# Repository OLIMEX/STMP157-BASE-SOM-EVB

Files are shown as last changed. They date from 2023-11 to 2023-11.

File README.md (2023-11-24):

# STMP157-BASE-SOM-EVB
Evaluation board for STMP157-BASE-SOM

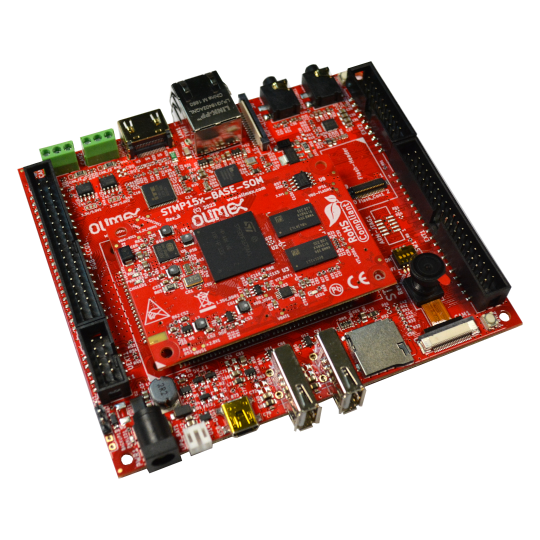
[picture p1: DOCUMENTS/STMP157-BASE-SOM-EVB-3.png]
STMP157-BASE-SOM-EVB-3


https://www.olimex.com/Products/SOM/STMP1/STMP157-BASE-SOM-EVB/open-source-hardware

## Features:

* 6 connectors for STMP157-BASE-SOM
* Two USB host 2.0
* USB-OTG
* Two CAN drivers
* HDMI output
* CSI OV2640-120 2Mpixel Camera
* Gigabit Ethernet
* MIPI LCD connector
* Microphone 3.5mm connector
* Headphones 3.5mm connector
* RESET button
* RGB LCD connector compatible with LCD-OLinuXino-5CTS, LCD-OLinuXino-7.0CTS, LCD-OLinuXino-10CTS
* UEXT connector
* EXT1, EXT2 connectors
* PWR connector
* LiPo charger and battery connector
* PWR LED
* DBG connector
* Flash module connector
* Boot configuration slide switch
* SD-card
* optional JTAG connector (not populated)
* Dimensions: 122 x 106 mm

## Licenses

* Hardware is released under CERN Open Hardware Licence Version 2 - Strongly Reciprocal, all silkscreen credits to Olimex should remain;
* Software is released under GPL3 Licensee
* Documentation is released under CC BY-SA 3.0

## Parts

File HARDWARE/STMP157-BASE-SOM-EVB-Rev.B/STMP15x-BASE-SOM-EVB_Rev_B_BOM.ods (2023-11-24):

Qty | Designation | Package | Designator
3 | 0R/R0402 | R_0402_5MIL_DWS | R86,R89,R90
1 | 10R/R0402 | R_0402_5MIL_DWS | R30
14 | 22R/R0402 | R_0402_5MIL_DWS | R12,R17,R18,R19,R22,R24,R41, R42,R67,R75,R76,R78,R81,R79
3 | 120R/R1206 | R_1206_5MIL_DWS | R37,R40,R50
3 | 330R/R0402 | R_0402_5MIL_DWS | R8,R46,R47
2 | 680R/R0402 | R_0402_5MIL_DWS | R48,R49
8 | 1k/R0402 | R_0402_5MIL_DWS | R55,R68,R69,R70,R71,R72, R74,R80
1 | 1.1k/1%/R0402 | R_0402_5MIL_DWS | R5
11 | 2.2k/R0402 | R_0402_5MIL_DWS | R3,R7,R9,R10,R11,R26,R27, R31,R34,R45,R51
1 | 5.6k/R0402 | R_0402_5MIL_DWS | R20
2 | 6.81k/1%/R0402 | R_0402_5MIL_DWS | R64,R65
1 | 8.25k/1%/R0402 | R_0402_5MIL_DWS | R4
22 | 10k/R0402 | R_0402_5MIL_DWS | R1,R6,R14,R16,R21,R25,R28, R29,R32,R33,R36,R39,R52,R57, R58,R59,R60,R62,R73,R77, R82,R85
1 | 12.1k/1%/R0603 | R_0603_5MIL_DWS | R53
1 | 13k/1%/R0402 | R_0402_5MIL_DWS | R63
2 | 100k/R0402 | R_0402_5MIL_DWS | R54,R83
1 | 1M/R0402 | R_0402_5MIL_DWS | R2
3 | RA0805_(4X0402)_22R | RA0805_(4X0402)_xx_BIGGEROUTPADS | RM1,RM3,RM4
1 | RA0805_(4X0402)_4.7k | RA0805_(4X0402)_xx_BIGGEROUTPADS | RM2
1 | RA1206_(4x0603)_4B8_100k | RA1206_(4X0603)_4B8_xx | RM5
2 | 33pF/50V/5%/COG/C0402 | C_0402_5MIL_DWS | C47,C48
1 | 1nF/2kV/10%/X7R/C1206 | C_1206_5MIL_DWS_ISO | C85
1 | 3.3nF/50V/10%/X5R/C0402 | C_0402_5MIL_DWS | C43
36 | 100nF/10V/10%/X5R/C0402 | C_0402_5MIL_DWS | C10,C11,C12,C14,C15,C17,C18, C19,C20,C21,C22,C23,C25,C28, C29,C33,C38,C39,C40,C41,C44, C45,C51,C53,C54,C56,C57,C59, C61,C62,C63,C77,C78,C79, C83,C84
1 | 1uF/10V/10%/X5R/C0603 | C_0603_5MIL_DWS | C64
7 | 10uF/6.3V/20%/X5R/C0603 | C_0603_5MIL_DWS | C7,C8,C26,C27,C34,C36,C37
10 | 22uF/6.3V/20%/X5R/C0603 | C_0603_5MIL_DWS | C1,C5,C9,C13,C16,C46,C49, C52,C58,C60
15 | 47uF/6.3V/20%/X5R/C0805 | C_0805_5MIL_DWS | C2,C3,C4,C30,C31,C35,C50, C55,C65,C66,C67,C68,C69, C70,C86
1 | 1N5822/SS34/SMA | SMA-KA | D1
1 | 1N4007/SMA | SMA-KA | D3
1 | 1N5819S4(SOD123) | SOD-123_1C-2A_KA | D4
1 | SMBJ6.0A | DO214AA_1(K)-2(A) | D2
1 | LED/Red/0603 | LED_0603_KA | PWRLED1
1 | 2.2uH/3A/YS75/7x8 | YS75_7X8MM | L1
9 | FB0805/600R/2A | L_0805_5MIL_DWS | L2,L3,L4,L5,L6,L7,L8,L9,L12
1 | BSS138(SOT-23) | SOT23 | FET2
2 | IRLML6402(SOT-23) | SOT23 | FET3,FET1
1 | Q25MHz/20pF/20ppm/ 4P/3.2x2.5mm | TSX-3.2x2.5mm_GND(3) | Q1
1 | FSMD035 | FUSE-1206 | FUSE2
2 | ESDS314DBVR(SOT-23-5) | SOT-23-5 | TVS1,TVS2
1 | IT66121FN(QFN-64) | QFN64_9x9mm_Pitch_0.5mm | U6
1 | KSZ9031RNXCC-TR/QFN48 | QFN48_1DRILL(PADPITCH-0.5MM) | U13
3 | SY6280AAC(SOT23-5) | SOT-23-5 | U10,U11,U12
2 | SIT1050T(SOIC-8_150mil) | SOIC-8_150mil | U8,U9
1 | MT3608(SOT23-6) | SOT23-6 | U2
1 | ES8388(QFN28) | QFN28_EP(29)_4.076x4.076x0.9m | U7
1 | VDA4510CTA(SOT23-3) | SOT-23 | U14
1 | LD1117AG-AD-AA3-A-R | SOT223 | VR1
1 | TFC-WPAPR-08-LF | TFC-WPAPR-08 | MICRO_SD1
1 | CAMERA-OV2640-120 (FPV-WZB21-24-LF) | OV2640(FPV-WZB21-24-LF) | CAM1
2 | USB_A_VERTICAL | USB_A_VERTICAL_PTH | USB1,USB2
1 | USB-OTG(MSB-SW-5AB-LF) | USB_MINI_9PIN | USB-OTG1
1 | DW02R | LIPO_BAT-CON2DW02R | LiPo_BAT1
1 | PWRJ-2mm(YDJ-1134) | PWRJ-2mm(YDJ-1134) | PWR1
1 | HN1x3 | HN1x3 | DBG1
2 | TB3-3.5mm(HD-351_3P) | TB3-3.5mm | CAN1,CAN2
1 | TM211Q01FM22 | TM211Q01FM22 | LAN1
1 | P-B-V-10-LF | GBH-254-SMT-10 | UEXT1
2 | P-B-V-40-LF | GBH-254-SMT-40 | EXT1,RGB-LCD1
1 | B-V-20-LF(GBH254SMT-20) | GBH-254-SMT-20 | EXT2
1 | FPA-VZA2-15-LF | TE_1-1734248-5 | MiPi-LCD1
2 | PJ-3.5-365-3P (SCJ325P00XG0B02G) | SCJ325P00XG0B02G | MICROPHONE1, HEADPHONES1
1 | DF12(3.0)-40DS-0.5V(51) | Flash_Con[DF12(3.0)-40DS-0.5V(86)] | Flash_Con1
6 | MALE-PAV16X-2x20-HIGH | GPH127SMT-02X20(PA-V16X-2X20-LF) | GPIO1,GPIO2,GPIO3,GPIO4, GPIO5,GPIO6
1 | HDMI-SWM-19 | HDMI-SWM-19 | HDMI1
1 | DSHP04TS-S | DSHP04TS-S-1.27mm_Half_4_Slide | BOOT_SW1
2 | YTS-A016-X | YTS-A016-X | RST1,PWR2
2 | Opened(2-3)/Closed(1-2) | SJ_2_SMALL_12_TIED | 3.3V/5.0V1,3.3V/5.0V2
3 | Opened | SJ_1_SMALLER | 5V_E1,CAN_T1,CAN_T2
1 | NA(10uF/6.3V/20%/X5R/C0603) | C_0603_5MIL_DWS | C6
2 | NA(100nF/10V/10%/X5R/C0402) | C_0402_5MIL_DWS | C32,C24
1 | NA(HN1X2) | HN1x2 | BACKUP1
1 | NA(15pF/C0402) | C_0402_5MIL_DWS | C42
2 | NA(2.2k/R0402) | R_0402_5MIL_DWS | R92,R91
10 | NA/R0402 | R_0402_5MIL_DWS | R61,R13,R15,R35,R38,R43,R44, R66,R56,R84
1 | NA(HAB-VCR-010-LF) | HAB-VCR-010-LF | ARM-JTAG1
3 | NA(24pF/50V/5%/COG/C0402) | C_0402_5MIL_DWS | C80,C82,C81
3 | NA(RCLAMP0524P(SLP2510P8)) | SLP2510P8_TEST | U5,U3,U4
1 | NA(22R/R0402) | R_0402_5MIL_DWS | R23
6 | NA(47uF/6.3V/20%/X5R/C0805) | C_0805_5MIL_DWS | C71,C72,C73,C74,C75,C76
1 | NA(5025) | FUSE-5025 | FUSE1
2 | NA(2.7nH/L0402) | L_0402_5MIL_DWS | L10,L11
1 | NA(MCP121T475I-TT(SOT23-3)) | SOT-23 | U1
4 | NA(560pF/50V/5%/NP0/C0603) | C_0603_5MIL_DWS | C87,C88,C89,C90
2 | NA(0R/R0402) | R_0402_5MIL_DWS | R87,R88

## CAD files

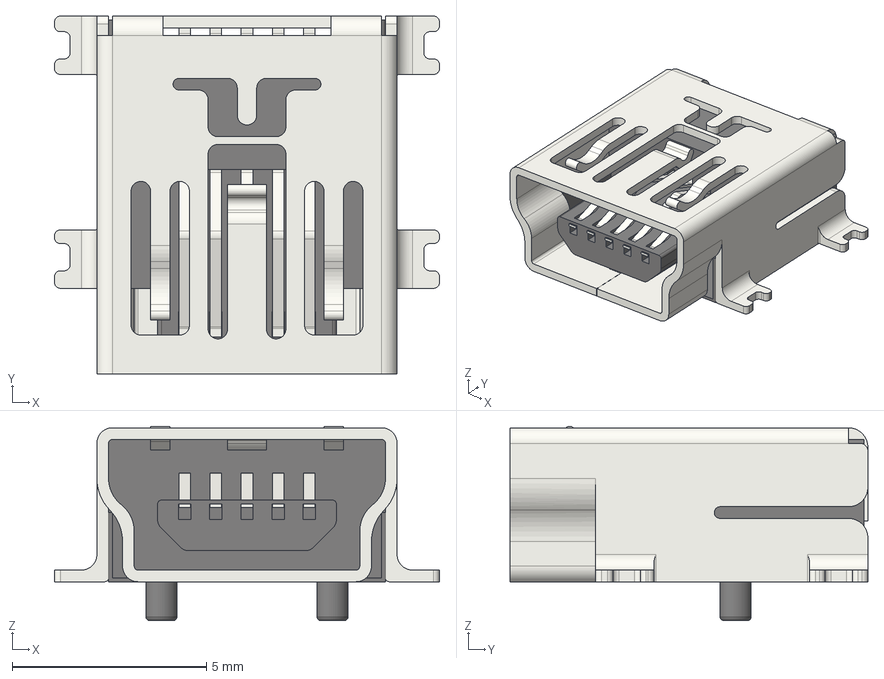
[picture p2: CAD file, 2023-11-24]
HARDWARE/STMP157-BASE-SOM-EVB-Rev.B/3d/USB_Mini-B_Lumberg_2486_01_Horizontal.step
9.90 x 9.20 x 5.00 mm

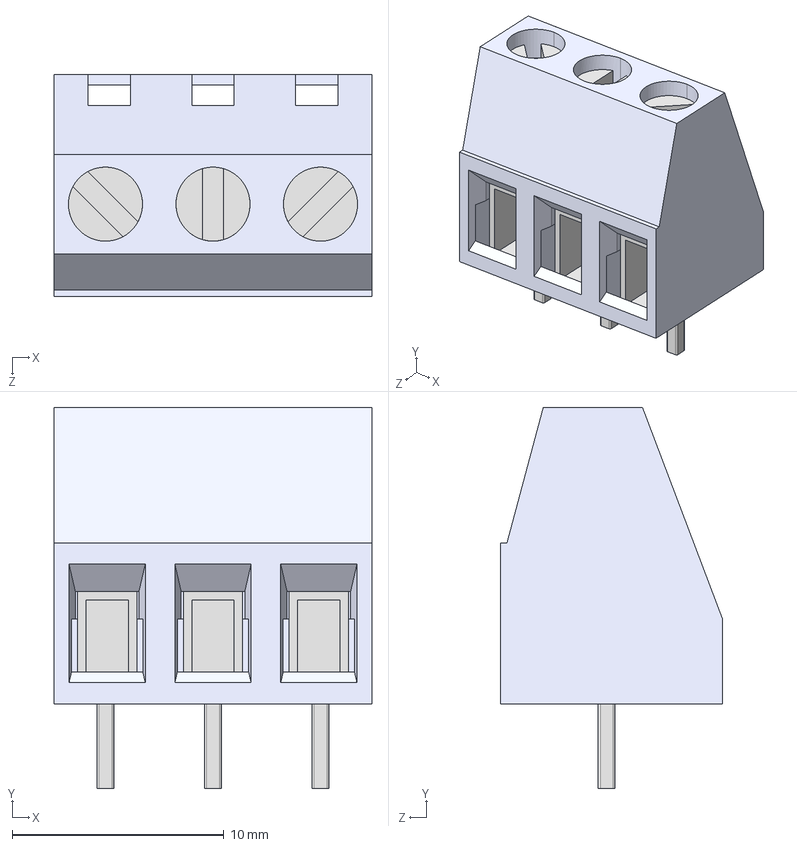
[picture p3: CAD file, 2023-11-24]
HARDWARE/STMP157-BASE-SOM-EVB-Rev.B/3d/klema-5mm-3pin.step
15.0 x 18.0 x 10.5 mm

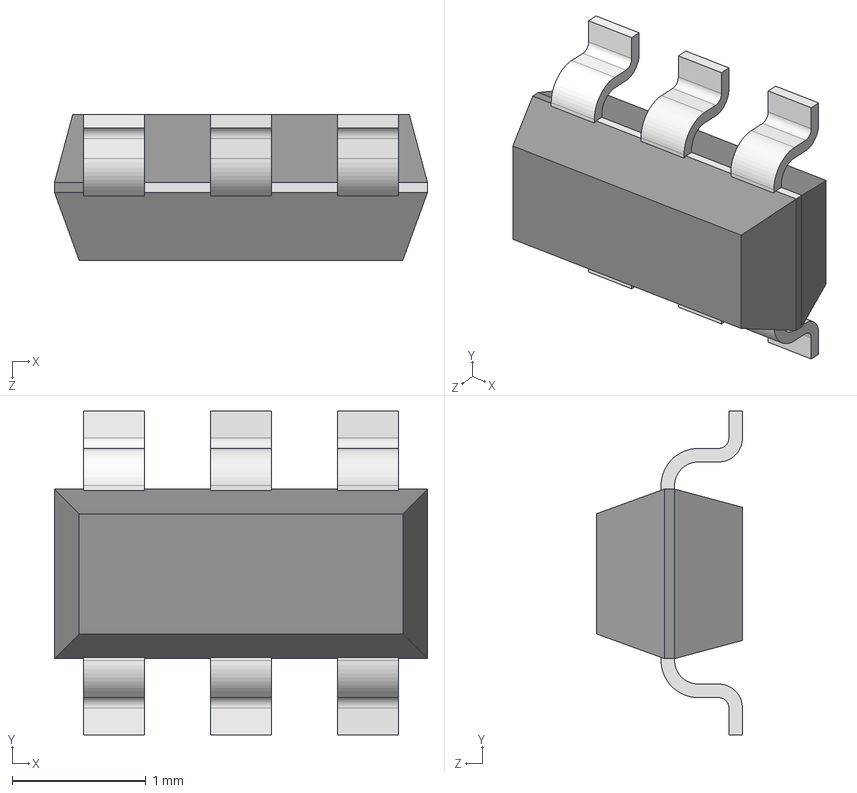
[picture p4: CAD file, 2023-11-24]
HARDWARE/STMP157-BASE-SOM-EVB-Rev.B/3d/SOT-23-6.step
2.79 x 2.43 x 1.09 mm

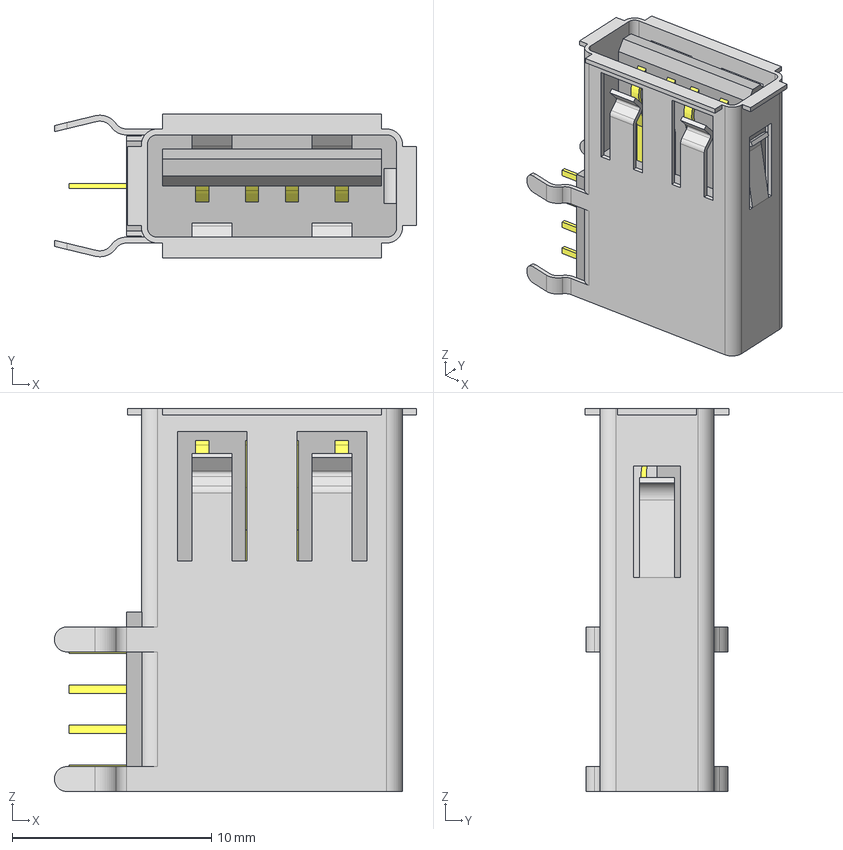
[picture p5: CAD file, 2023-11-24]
HARDWARE/STMP157-BASE-SOM-EVB-Rev.B/3d/USB-A-S-F-B-VU.stp
18.2 x 7.20 x 19.2 mm
_USB-A-S-VU_S
_USB-A-S-B-VU_B
_USB-A-S-VU_P

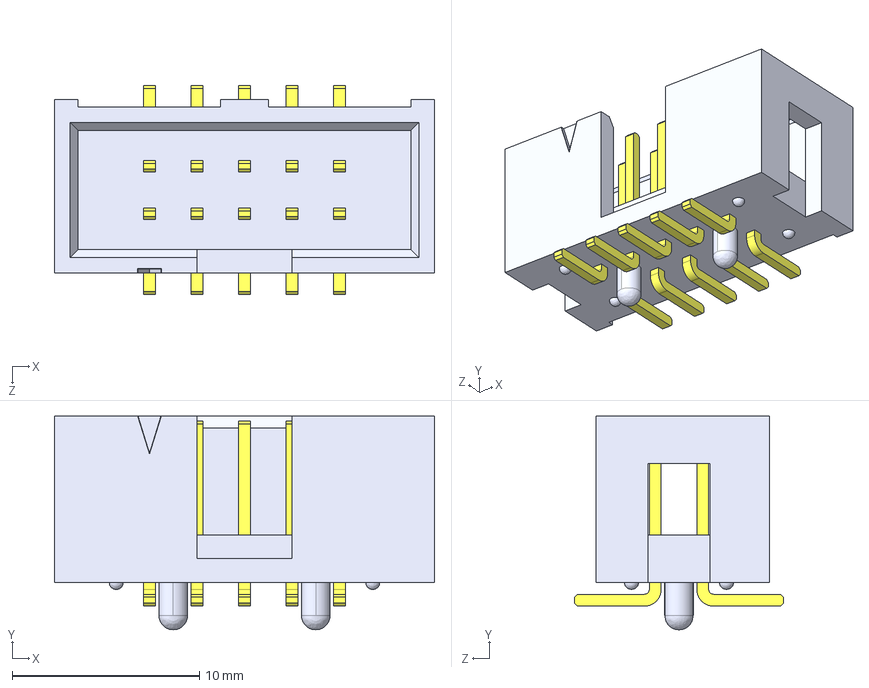
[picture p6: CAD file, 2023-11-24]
HARDWARE/STMP157-BASE-SOM-EVB-Rev.B/3d/UEXT-SMD.STEP
20.3 x 11.4 x 11.2 mm
User Library-HTST-105-01-F-DV-A__HTST-105-01-DV-A_header
User Library-HTST-105-01-F-DV-A__HTST-First_Position_Indicator
User Library-HTST-105-01-F-DV-A__T-1S6-05-01-DV_

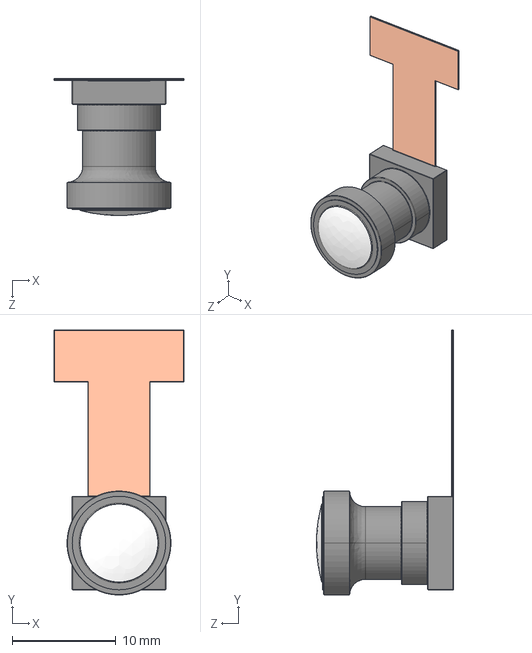
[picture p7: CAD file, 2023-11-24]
HARDWARE/STMP157-BASE-SOM-EVB-Rev.B/3d/OV2640.STEP
12.5 x 25.5 x 13.2 mm

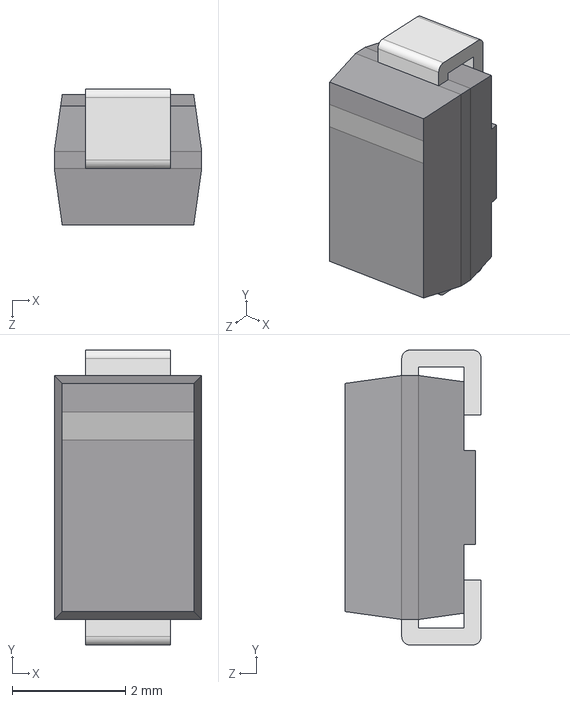
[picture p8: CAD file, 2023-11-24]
HARDWARE/STMP157-BASE-SOM-EVB-Rev.B/3d/DO-214AC_SMA.step
2.60 x 5.20 x 2.40 mm

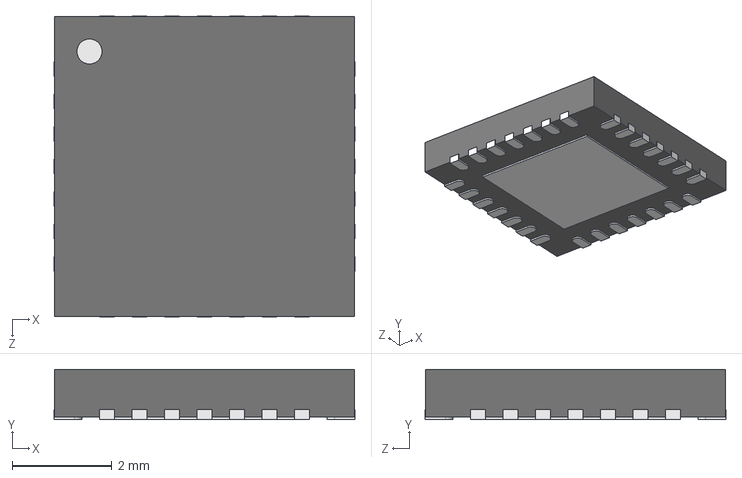
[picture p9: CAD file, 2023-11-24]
HARDWARE/STMP157-BASE-SOM-EVB-Rev.B/3d/QFN-28(6.0x6.0x1.0mm_P0.65mm).STEP
6.02 x 1.00 x 6.02 mm

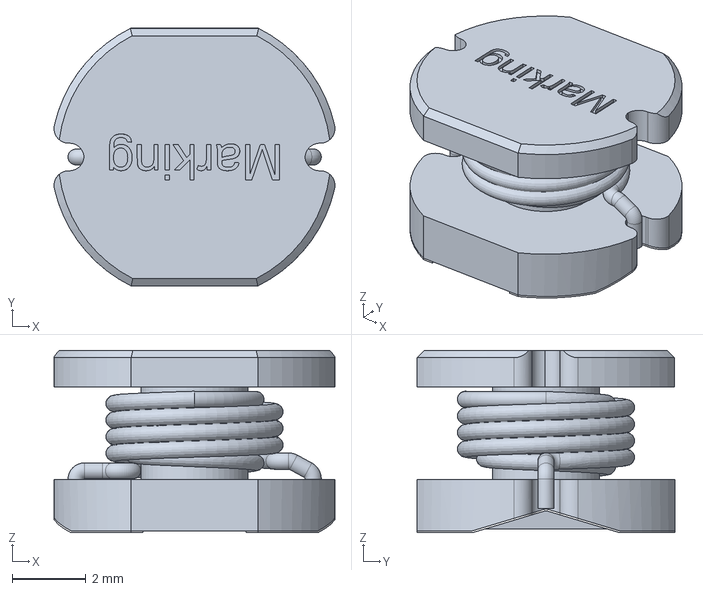
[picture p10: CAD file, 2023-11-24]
HARDWARE/STMP157-BASE-SOM-EVB-Rev.B/3d/L-CD75(YS75)_7.80x7.00x5.50mm.step
7.63 x 7.00 x 4.95 mm

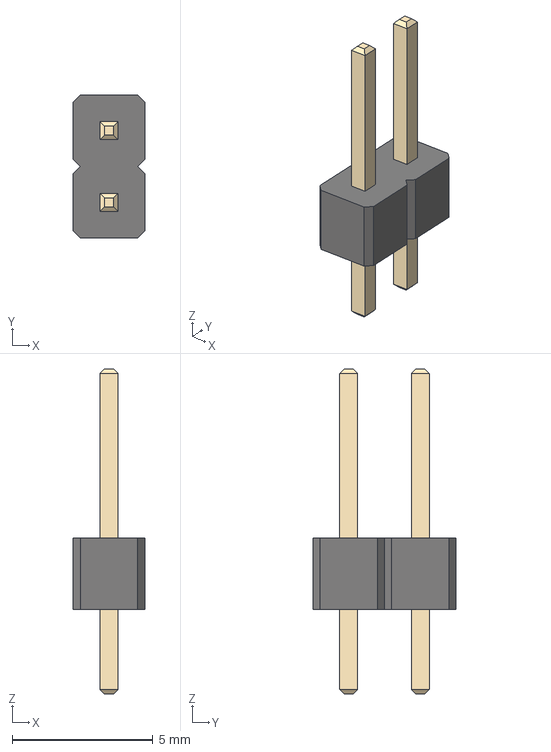
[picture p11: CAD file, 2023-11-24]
HARDWARE/STMP157-BASE-SOM-EVB-Rev.B/3d/HN1x2-PinHeader_1x02_P2.54mm_Vertical.step
2.54 x 5.08 x 11.5 mm

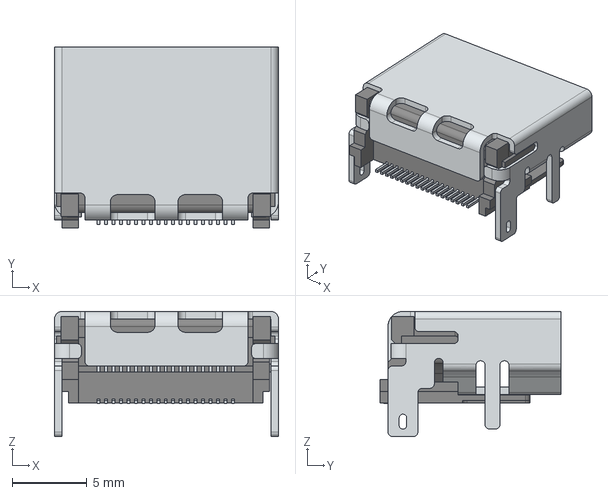
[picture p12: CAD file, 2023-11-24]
HARDWARE/STMP157-BASE-SOM-EVB-Rev.B/3d/HDMI_19POS_SMD_Wurth_Electronic-685119134923.stp
15.0 x 12.2 x 8.38 mm

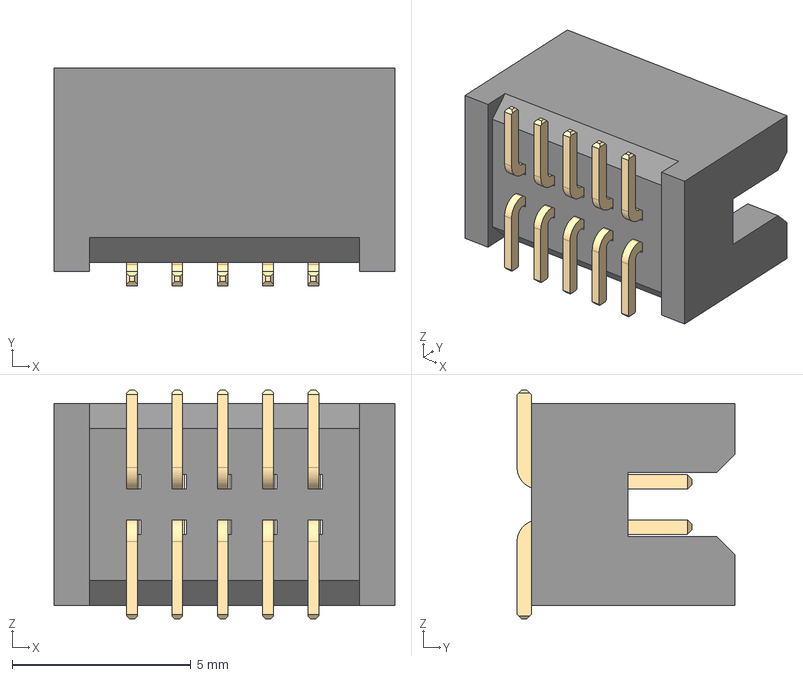
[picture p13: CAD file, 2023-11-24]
HARDWARE/STMP157-BASE-SOM-EVB-Rev.B/3d/GBH2x5.stp
9.55 x 6.10 x 6.40 mm

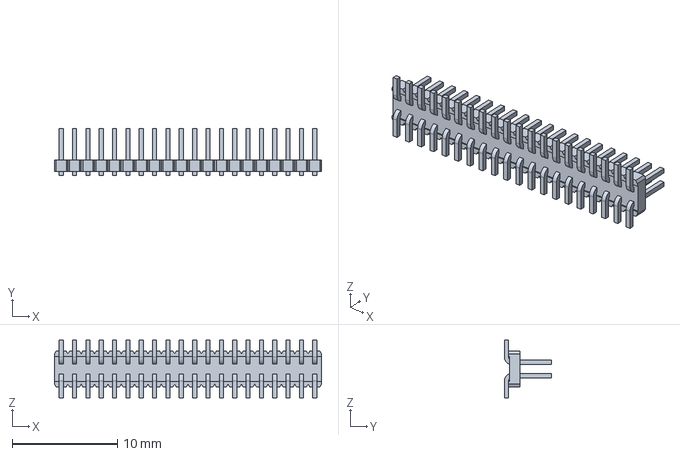
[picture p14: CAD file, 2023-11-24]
HARDWARE/STMP157-BASE-SOM-EVB-Rev.B/3d/40PinMaleSMD.stp
25.4 x 4.50 x 5.50 mm

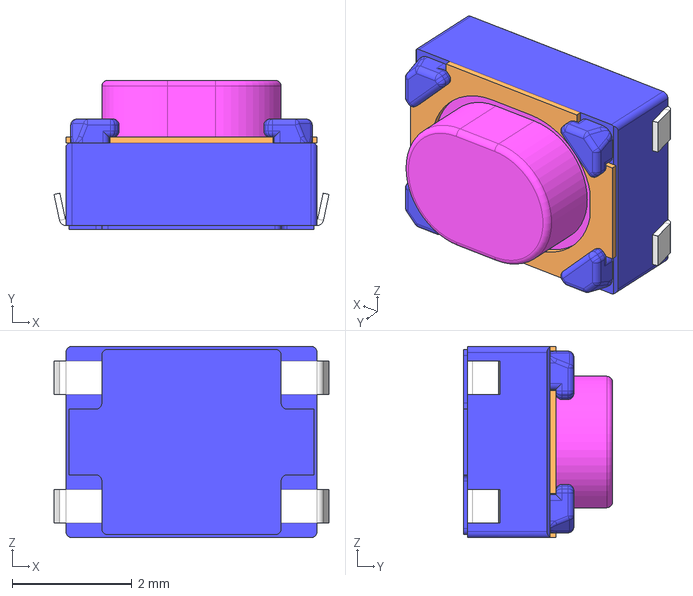
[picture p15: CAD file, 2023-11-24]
HARDWARE/STMP157-BASE-SOM-EVB-Rev.B/3d/YTS-A016-X(SKRPABE010).stp
4.60 x 2.50 x 3.20 mm

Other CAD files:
HARDWARE/STMP157-BASE-SOM-EVB-Rev.B/3d/SOT-23.step
HARDWARE/STMP157-BASE-SOM-EVB-Rev.B/3d/HN1x3-PinHeader_1x03_P2.54mm_Vertical.step
HARDWARE/STMP157-BASE-SOM-EVB-Rev.B/3d/dshp04ts-s.stp
HARDWARE/STMP157-BASE-SOM-EVB-Rev.B/3d/QFN48-0.5.STEP
HARDWARE/STMP157-BASE-SOM-EVB-Rev.B/3d/Audio_Jack-3.5mm---CUI_SJ1-3515-SMT-TR.step
HARDWARE/STMP157-BASE-SOM-EVB-Rev.B/3d/Connector_1Port_RJ45_Magjack_10-100Base-T_AutoMDIX_Molex-0934635206_DigiKey-WM17614-ND.stp
HARDWARE/STMP157-BASE-SOM-EVB-Rev.B/3d/DF12(3.0)-40DS-0.5V.stp
HARDWARE/STMP157-BASE-SOM-EVB-Rev.B/3d/DO-214AA_SMB.step
HARDWARE/STMP157-BASE-SOM-EVB-Rev.B/3d/FPV-WZB21-24-LF_Molex-524372433.stp
HARDWARE/STMP157-BASE-SOM-EVB-Rev.B/3d/GBH254SMT-20(B-V-20-LF)---CH8720xM100.STEP
HARDWARE/STMP157-BASE-SOM-EVB-Rev.B/3d/GBH254SMT-40(B-V-40-LF).stp
HARDWARE/STMP157-BASE-SOM-EVB-Rev.B/3d/JST_B2B-PH-SM4-TB(DW02R).step
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

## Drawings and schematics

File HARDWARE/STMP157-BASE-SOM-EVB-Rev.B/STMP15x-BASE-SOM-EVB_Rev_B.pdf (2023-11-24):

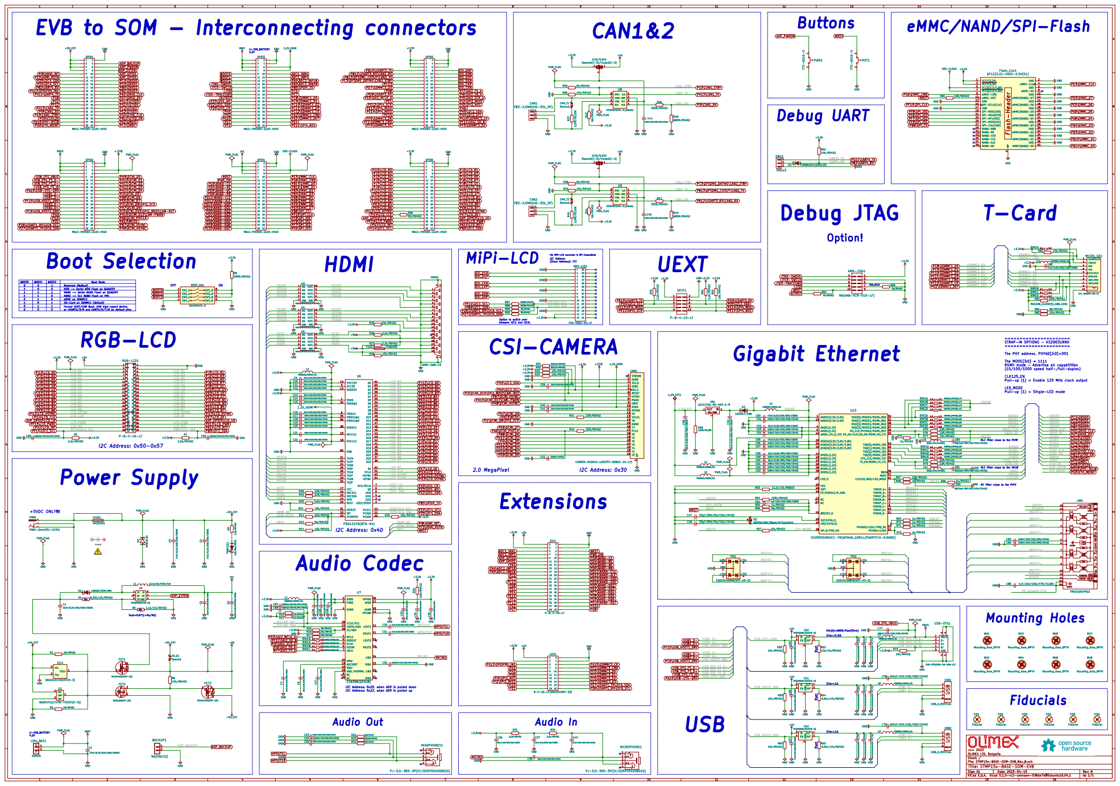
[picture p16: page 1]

+2V8 EVB to SOM - Interconnecting connectors
9GPIO1 MALE-PAV16X-2x20-HIGH

eMMC/NAND/SPI-Flash

Forced UART/USB Boot. USB high-speed device,

====================== The PHY address, PHYAD[2:0]=001

The MODE[3:0] = 1111
RGMII mode - Advertise all capabilities
(10/100/1000 speed half-/full-duplex)

CLK125_EN
Pull-up (1) = Enable 125 MHz clock output

LED_MODE
Pull-up (1) = Single-LED mode

DA+ DA- DB+ DB- DC+ DC- DD+ DD- GREEN

LIN1 24 NC 25 CE/AD0 26 CDATA/SDA 27 CCLK/SCL 28 GND_THERMAL 29 PVDD 3 DGND 4 SCLK 5 DSDIN 6
LOUT1 12 HPGND 13 ROUT2 14

USB-OTG(MSB-SW-5AB-LF) VBUS GND PA15\USB-OTG-DRV

Ilim(A)=6800/Rset(Ohm) Rset

GND 3 U1 NA(MCP121T475I-TT(SOT23-3)) GND

I2C Address: 0x20, when AD0 is pulled down
I2C Address: 0x22, when AD0 is pulled up

File: STMP15x-BASE-SOM-EVB_Rev_B.sch Sheet: / OLIMEX LTD, Bulgaria <c> 2023

Id: 1/1 Title: STMP15x-BASE-SOM-EVB

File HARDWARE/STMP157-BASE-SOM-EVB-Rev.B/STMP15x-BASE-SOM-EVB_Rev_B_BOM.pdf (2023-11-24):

STMP15x-BASE-SOM-EVB_Rev_B | 04/12/2023

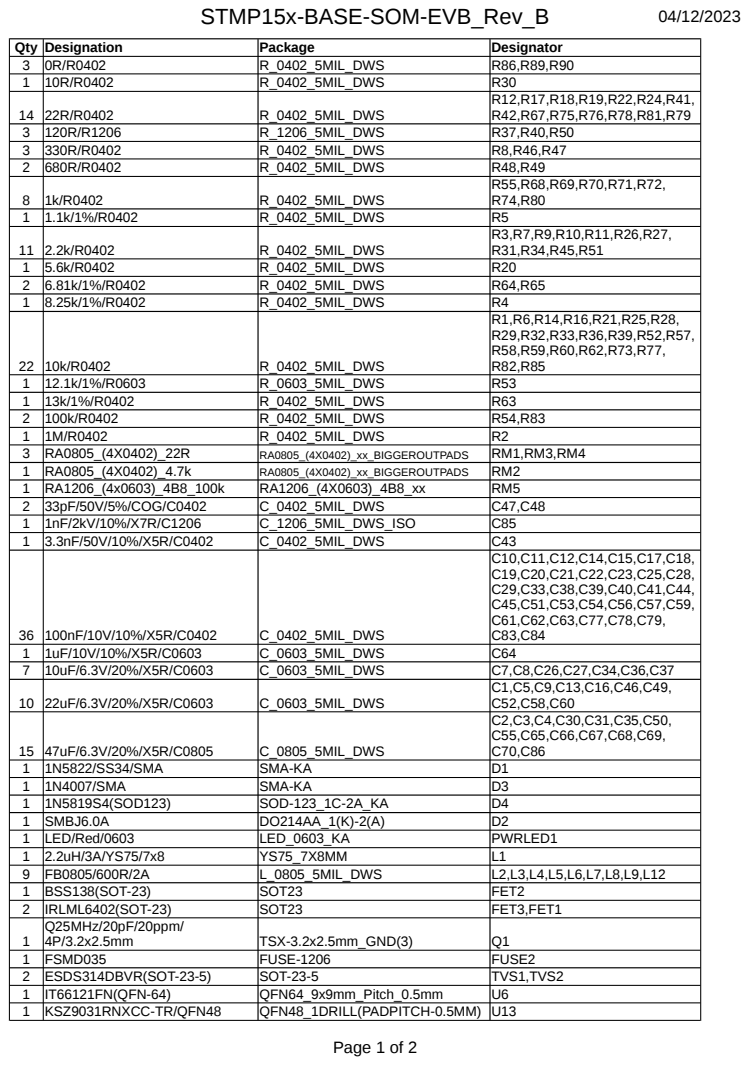
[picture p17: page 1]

STMP15x-BASE-SOM-EVB_Rev_B | 04/12/2023

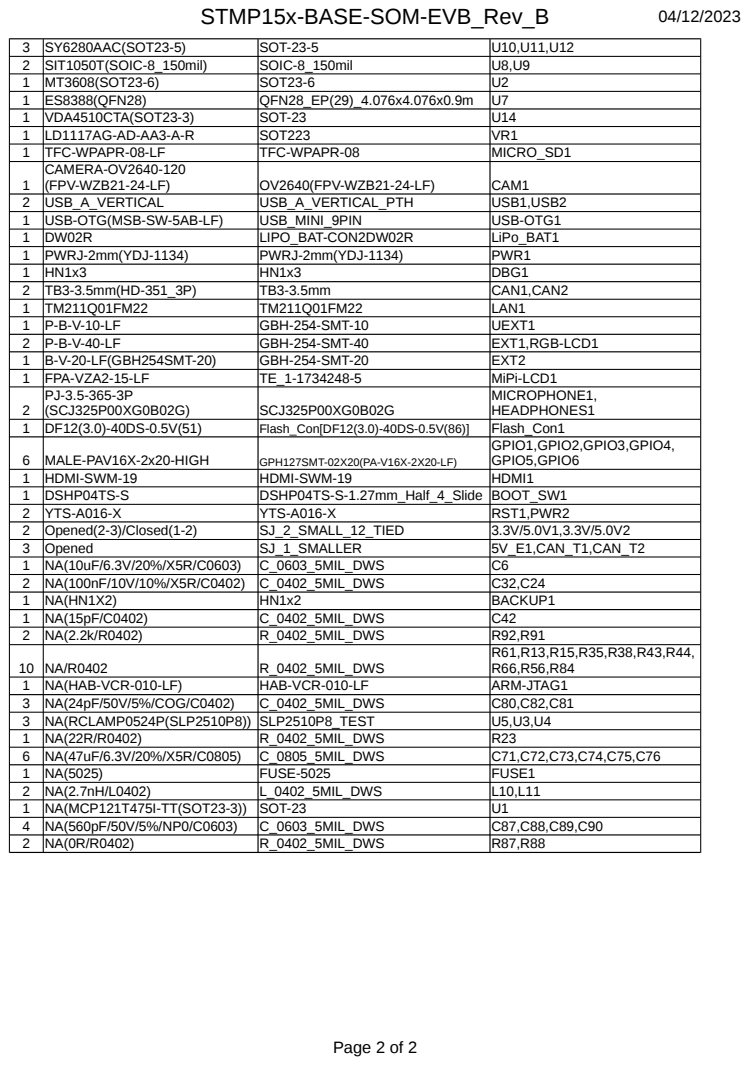
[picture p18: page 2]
3 SY6280AAC(SOT23-5); SOT-23-5; 2 SIT1050T(SOIC-8_150mil); SOIC-8_150mil; 1 MT3608(SOT23-6); SOT23-6; 1 ES8388(QFN28); QFN28_EP(29)_4.076x4.076x0.9m U7; 1 VDA4510CTA(SOT23-3); SOT-23; SOT223; 1 TFC-WPAPR-08-LF; TFC-WPAPR-08; MICRO_SD1; OV2640(FPV-WZB21-24-LF); CAM1; 2 USB_A_VERTICAL; USB_A_VERTICAL_PTH; USB1,USB2; 1 USB-OTG(MSB-SW-5AB-LF); USB_MINI_9PIN; USB-OTG1; LIPO_BAT-CON2DW02R; LiPo_BAT1; 1 PWRJ-2mm(YDJ-1134); PWRJ-2mm(YDJ-1134); PWR1; DBG1; CAN1,CAN2; LAN1; GBH-254-SMT-10; UEXT1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

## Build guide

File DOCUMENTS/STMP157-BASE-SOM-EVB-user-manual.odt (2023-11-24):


STMP157-BASE-SOM-EVB

User Manual

Rev.1.0 November 2023 olimex.com

# What is STMP157-BASE-SOM-EVB

STMP157-BASE-SOM-EVB (https://www.olimex.com/Products/SOM/STMP1/STMP157-BASE-SOM-EVB/open-source-hardware) is evaluation board for STMP157-BASE-SOM- (https://www.olimex.com/Products/SOM/STMP1/STMP157-BASE-SOM-EXT/)EXT (https://www.olimex.com/Products/SOM/STMP1/STMP157-BASE-SOM-EXT/) system on module with STM32MP157DAA1 Dual Core Cortex A7 running @800Mhz + Cortex-M4 co-processor running at 209Mhz.

STM32MP157DAA1 targets industrial application and have plenty of features:

- Core
  - 32-bit dual-core Arm® Cortex®-A7
    - L1 32-Kbyte I / 32-Kbyte D for each core
    - 256-Kbyte unified level 2 cache
    - Arm® NEON™ and Arm® TrustZone®
  - 32-bit Arm® Cortex®-M4 with FPU/MPU
    - Up to 209 MHz (Up to 703 CoreMark®)
- Memories
  - External DDR memory up to 1 Gbyte
    - up to LPDDR2/LPDDR3-1066 16/32-bit
    - up to DDR3/DDR3L-1066 16/32-bit
  - 708 Kbytes of internal SRAM: 256 Kbytes of AXI SYSRAM + 384 Kbytes of AHB SRAM + 64 Kbytes of AHB SRAM in Backup domain and 4 Kbytes of SRAM in Backup domain
  - Dual mode Quad-SPI memory interface
  - Flexible external memory controller with up to 16-bit data bus: parallel interface to connect external ICs and SLC NAND memories with up to 8-bit ECC
- Security/safety
  - TrustZone® peripherals, active tamper
  - Cortex®-M4 resources isolation
- Reset and power management
  - 1.71 V to 3.6 V I/Os supply (5 V-tolerant I/Os)
  - POR, PDR, PVD and BOR
  - On-chip LDOs (RETRAM, BKPSRAM, DSI 1.2 V, USB 1.8 V, 1.1 V)
  - Backup regulator (~0.9 V)
  - Internal temperature sensors
  - Low-power modes: Sleep, Stop and Standby
  - DDR memory retention in Standby mode
  - Controls for PMIC companion chip
- Low-power consumption
  - Total current consumption down to 2 µA (Standby mode, no RTC, no LSE, no BKPSRAM, no RETRAM)
- Clock management
  - Internal oscillators: 64 MHz HSI oscillator, 4 MHz CSI oscillator, 32 kHz LSI oscillator
  - External oscillators: 8-48 MHz HSE oscillator, 32.768 kHz LSE oscillator
  - 6 × PLLs with fractional mode
- General-purpose input/outputs
  - Up to 176 I/O ports with interrupt capability
    - Up to 8 secure I/Os
    - Up to 6 Wakeup, 3 tampers, 1 active tamper
- Interconnect matrix
  - 2 bus matrices
    - 64-bit Arm® AMBA® AXI interconnect, up to 266 MHz
    - 32-bit Arm® AMBA® AHB interconnect, up to 209 MHz
- 3 DMA controllers to unload the CPU
  - 48 physical channels in total
  - 1 × high-speed general-purpose master direct memory access controller (MDMA)
  - 2 × dual-port DMAs with FIFO and request router capabilities for optimal peripheral management
- Up to 37 communication peripherals
  - 6 × I²C FM+ (1 Mbit/s, SMBus/PMBus)
  - 4 × UART + 4 × USART (12.5 Mbit/s, ISO7816 interface, LIN, IrDA, SPI slave)
  - 6 × SPI (50 Mbit/s, including 3 with full duplex I²S audio class accuracy via internal audio PLL or external clock)
  - 4 × SAI (stereo audio: I²S, PDM, SPDIF Tx)
  - SPDIF Rx with 4 inputs
  - HDMI-CEC interface
  - MDIO Slave interface
  - 3 × SDMMC up to 8-bit (SD / e•MMC™/ SDIO)
  - 2 × CAN controllers supporting CAN FD protocol, out of which one supports time-triggered CAN (TTCAN)
  - 2 × USB 2.0 high-speed Host+ 1 × USB 2.0 full-speed OTG simultaneously
    - or 1 × USB 2.0 high-speed Host+ 1 × USB 2.0 high-speed OTG simultaneously
  - 10/100M or Gigabit Ethernet GMAC
    - IEEE 1588v2 hardware, MII/RMII/GMII/RGMII
  - 8- to 14-bit camera interface up to 140 Mbyte/s
- 6 analog peripherals
  - 2 × ADCs with 16-bit max. resolution (12 bits up to 4.5 Msps, 14 bits up to 4 Msps, 16 bits up to 3.6 Msps)
  - 1 × temperature sensor
  - 2 × 12-bit D/A converters (1 MHz)
  - 1 × digital filters for sigma delta modulator (DFSDM) with 8 channels/6 filters
  - Internal or external ADC/DAC reference VREF+
- Graphics
  - 3D GPU: Vivante® - OpenGL® ES 2.0
    - Up to 26 Mtriangle/s, 133 Mpixel/s
  - LCD-TFT controller, up to 24-bit // RGB888
    - up to WXGA (1366 × 768) @60 fps or up to Full HD (1920 × 1080) @30 fps
    - Pixel clock up to 90 MHz
    - Two layers with programmable colour LUT
  - MIPI® DSI 2 data lanes up to 1 Gbps each
- Up to 29 timers and 3 watchdogs
  - 2 × 32-bit timers with up to 4 IC/OC/PWM or pulse counter and quadrature (incremental) encoder input
  - 2 × 16-bit advanced motor control timers
  - 10 × 16-bit general-purpose timers (including 2 basic timers without PWM)
  - 5 × 16-bit low-power timers
  - RTC with sub-second accuracy and hardware calendar
  - 2 × 4 Cortex®-A7 system timers (secure, non-secure, virtual, hypervisor)
  - 1 × SysTick M4 timer
  - 3 × watchdogs (2 × independent and window)
- Hardware acceleration
  - HASH (MD5, SHA-1, SHA224, SHA256), HMAC
  - 2 × true random number generator (3 oscillators each)
  - 2 × CRC calculation unit
- Debug mode
  - Arm® CoreSight™ trace and debug: SWD and JTAG interfaces
  - 8-Kbyte embedded trace buffer
- 3072-bit fuses including 96-bit unique ID, up to 1184-bit available for user
- All packages are ECOPACK2 compliant

# STMP157-BASE-SOM-EVB features:

STMP157-BASE-SOM- (https://www.olimex.com/Products/SOM/STMP1/STMP157-BASE-SOM-EXT/)EXT (https://www.olimex.com/Products/SOM/STMP1/STMP157-BASE-SOM-EXT/) exposes all STM32MP157DAA1 GPIOs and features in very compact format. It takes care for power supply and high speed memory signals complexities. STM157-BASE-SOM-EVB allow all features to be tested:

- 6 connectors for STMP157-BASE-SOM
- Two USB host 2.0
- USB-OTG
- Two CAN drivers and connectors
- HDMI output
- CSI OV2640-120 2M pixel camera
- Gigabit Ethernet
- MIPI LCD connector
- Audio CODEC
- Microphone 3.5mm connector
- Headphones 3.5mm connector
- RESET button
- RGB LCD connector compatible with LCD-OLinuXino-5CTS, LCD-OLinuXino-7.0CTS, LCD-OLinuXino-10CTS
- UEXT connector
- EXT1, EXT2 connectors
- PWR connector
- LiPo charger and battery connector
- PWR LED
- DBG connector
- Flash module connector
- Boot configuration slide switch
- SD-card
- optional JTAG connector (not populated)
- Dimensions: 122 x 106 mm

## Order codes for STMP157-BASE-SOM-EVB and accessories:

STMP157-BASE-SOM- (https://www.olimex.com/Products/SOM/STMP1/STMP157-BASE-SOM-EXT/)EXT (https://www.olimex.com/Products/SOM/STMP1/STMP157-BASE-SOM-EXT/) system on module with 1GB RAM, EEPROM, PMIC

STMP157-BASE-SOM-EVB (https://www.olimex.com/Products/SOM/STMP1/STMP157-BASE-SOM-EVB/open-source-hardware) evaluation board for STMP157-BASE-SOM- (https://www.olimex.com/Products/SOM/STMP1/STMP157-BASE-SOM-EXT/)EXT (https://www.olimex.com/Products/SOM/STMP1/STMP157-BASE-SOM-EXT/) which can be used as reference design

MICRO-SD-16GB-CLASS10 (https://www.olimex.com/Products/Components/Storage/MICRO-SD-16GB-CLASS10/) 16GB microSD card

SY1005 (https://www.olimex.com/Products/Power/SY1005E/)E (https://www.olimex.com/Products/Power/SY1005E/) power adapter 5V 2A

USB-SERIAL-F (https://www.olimex.com/Products/Components/Cables/USB-Serial-Cable/USB-SERIAL-F/) serial debug cable for console log

CABLE-HDMI-50CM (https://www.olimex.com/Products/Components/Cables/CABLE-HDMI-50CM/) HDMI cable

BATTERY-LIPO1400mAh (https://www.olimex.com/Products/Power/Lipo-battery/BATTERY-LIPO1400mAh/) LiPo battery for standalone operation

LCD/LCD-O (https://www.olimex.com/Products/OLinuXino/LCD/LCD-OLinuXino-5CTS/)L (https://www.olimex.com/Products/OLinuXino/LCD/LCD-OLinuXino-5CTS/)inuXino-5CTS (https://www.olimex.com/Products/OLinuXino/LCD/LCD-OLinuXino-5CTS/) 5 inch LCD 800x480 pixels with capacitive touch panel

LCD-O (https://www.olimex.com/Products/OLinuXino/LCD/LCD-OLinuXino-7CTS/open-source-hardware)L (https://www.olimex.com/Products/OLinuXino/LCD/LCD-OLinuXino-7CTS/open-source-hardware)inuXino-7CTS (https://www.olimex.com/Products/OLinuXino/LCD/LCD-OLinuXino-7CTS/open-source-hardware) 7 inch LCD 1024x600 pixels with capacitive touch panel

LCD-OLinuXino-10CTS (https://www.olimex.com/Products/OLinuXino/LCD/LCD-OLinuXino-10CTS/open-source-hardware) 10 inch LCD 1024x600 pixels with capacitive touch panel

UEXT modules (https://www.olimex.com/Products/Modules/) There are temperature, humidity, pressure, magnetic field, light sensors. Modules with LCDs, LED matrix, Relays, Bluetooth, Zigbee, WiFi, GSM, GPS, RFID, RTC, EKG, sensors and etc.

# HARDWARE

## STMP157-BASE-SOM-EVB layout:

MIPI

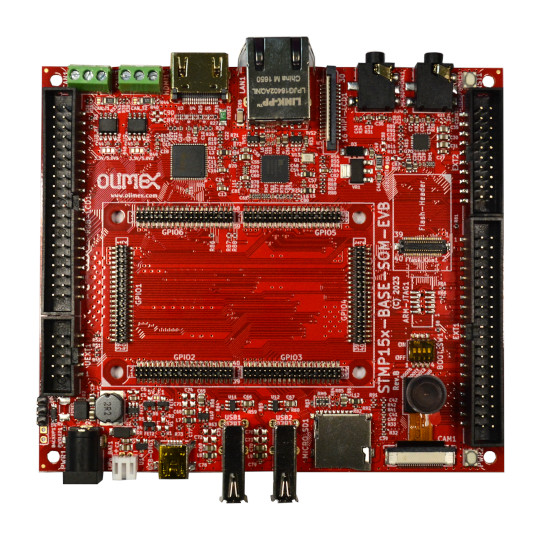
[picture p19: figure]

CAN1 CAN2

HDMI

LAN

MIC

headphones

RESET

Audio codec

EXT2

Flash module

LCD

JTAG

EXT1

STMP157-BASE-SOM

Boot config

CSI 2Mpix camera

POWER

Micro SD card

USB 2.0 Host x2

USB-OTG

LiPo

PWR +5V

Debug

UEXT

## STMP157-BASE-SOM-EVB schematics:

STMP157-BASE-SOM- (https://www.olimex.com/Products/SOM/STMP1/STMP157-BASE-SOM-EXT/)EVB (https://www.olimex.com/Products/SOM/STMP1/STMP157-BASE-SOM-EXT/) latest schematic is on GitHub (https://github.com/OLIMEX/STMP157-BASE-SOM-EVB/blob/main/HARDWARE/STMP157-BASE-SOM-EVB-Rev.B/STMP15x-BASE-SOM-EVB_Rev_B.pdf)

STMP157-BASE-SOM- (https://www.olimex.com/Products/SOM/STMP1/STMP157-BASE-SOM-EXT/)EVB (https://www.olimex.com/Products/SOM/STMP1/STMP157-BASE-SOM-EXT/) is Open Source Hardware and all source CAD files are on GitHub (https://github.com/OLIMEX/STMP157-BASE-SOM-EVB).

# SOFTWARE

# Recommended Olimage Linux images (http://images.olimex.com/release/stm32-som/) and changelog (https://images.olimex.com/changelog.txt)

# Olimage Linux guide (https://github.com/OLIMEX/OLINUXINO/blob/master/DOCUMENTS/OLIMAGE/Olimage-guide.pdf)

# Revision History

Revision 1.0 November 2023 initial

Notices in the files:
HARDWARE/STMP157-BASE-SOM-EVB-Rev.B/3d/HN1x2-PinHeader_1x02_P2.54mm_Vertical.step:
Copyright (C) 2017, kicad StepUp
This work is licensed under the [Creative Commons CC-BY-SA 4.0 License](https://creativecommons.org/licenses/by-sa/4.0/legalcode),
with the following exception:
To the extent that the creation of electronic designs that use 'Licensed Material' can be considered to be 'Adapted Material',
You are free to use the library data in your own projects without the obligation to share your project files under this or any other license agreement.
